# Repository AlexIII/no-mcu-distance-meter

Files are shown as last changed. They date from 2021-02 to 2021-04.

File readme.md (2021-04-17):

# No-MCU Ultrasonic Distance Meter

A Distance Meter that uses no MCU. Bases on ultrasonic ranging module [HC-SR04](https://cdn.sparkfun.com/datasheets/Sensors/Proximity/HCSR04.pdf).

The schematic employs just three standard logic ICs (8-bit counter, divider/oscillator, quad NAND) and a ROM chip (acts as a binary-to-decimal converter).

## Schematic

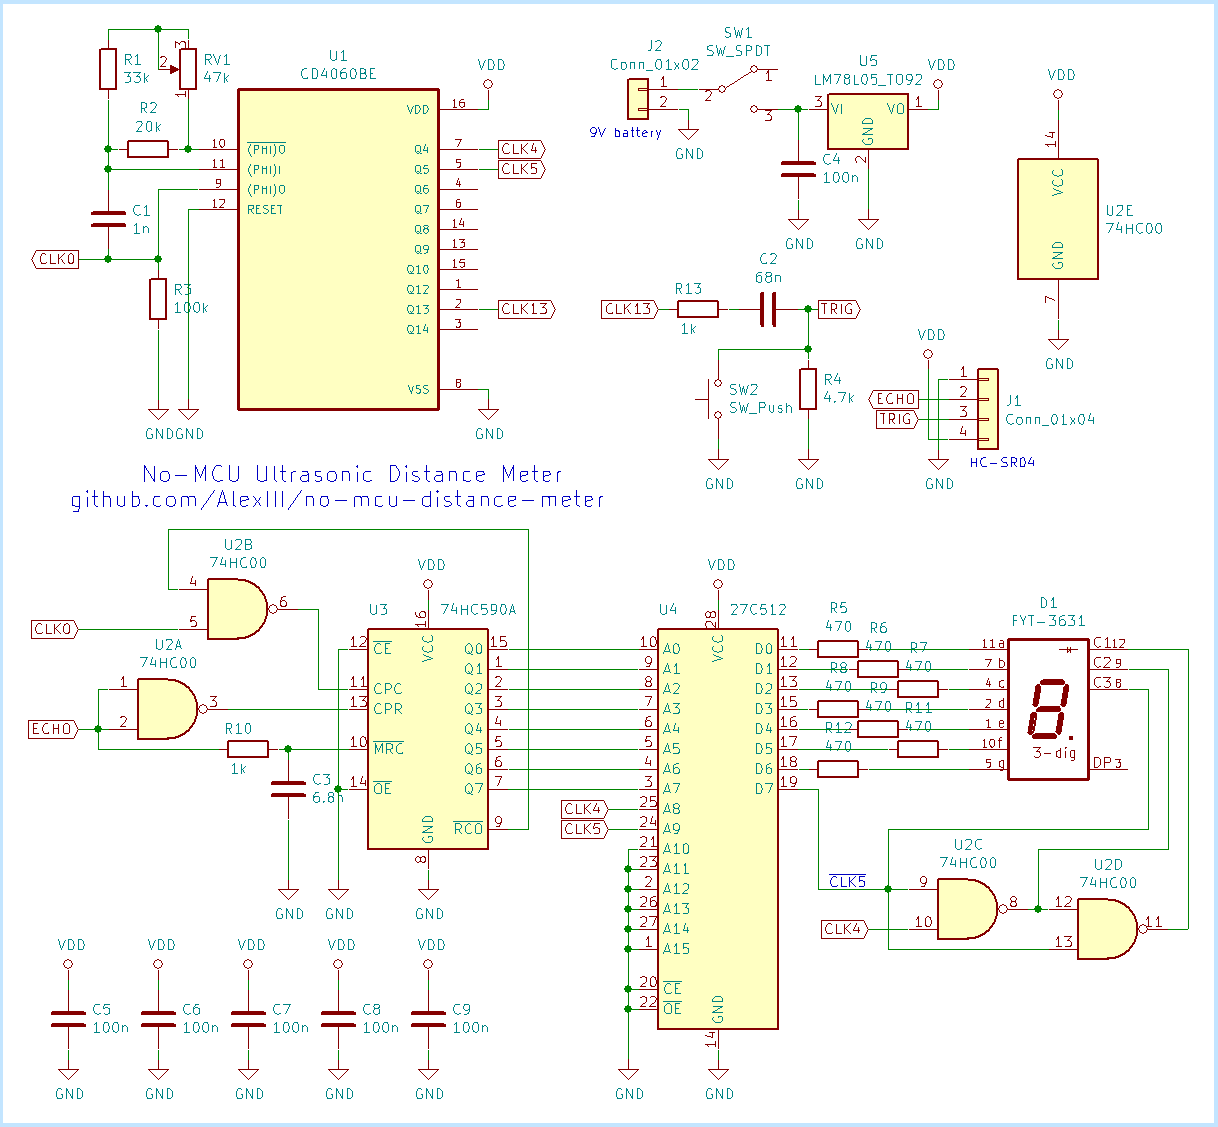
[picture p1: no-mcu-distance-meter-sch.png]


## Photos

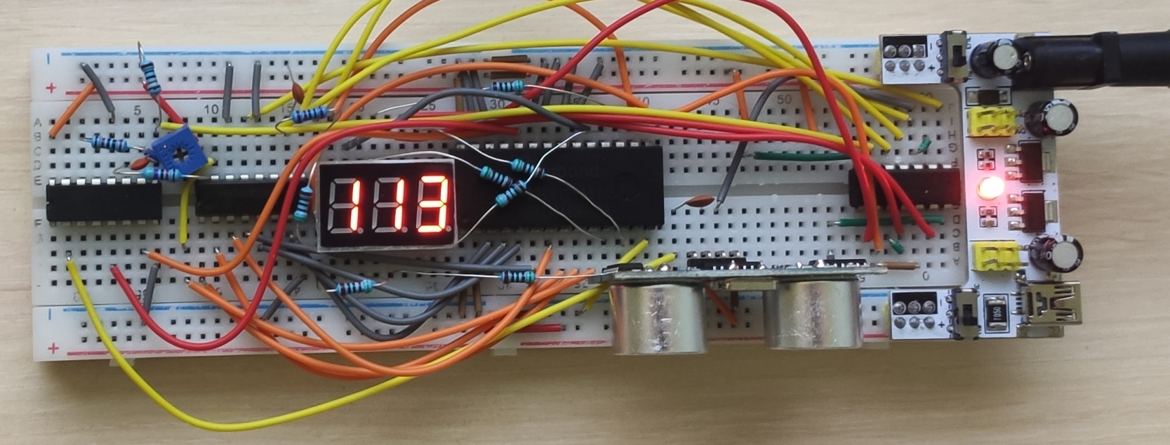
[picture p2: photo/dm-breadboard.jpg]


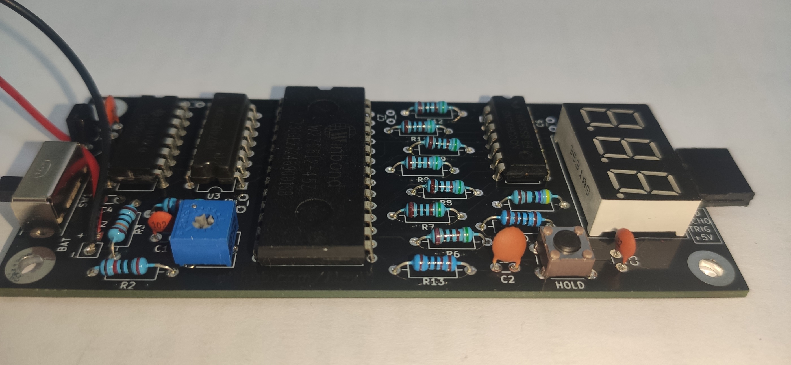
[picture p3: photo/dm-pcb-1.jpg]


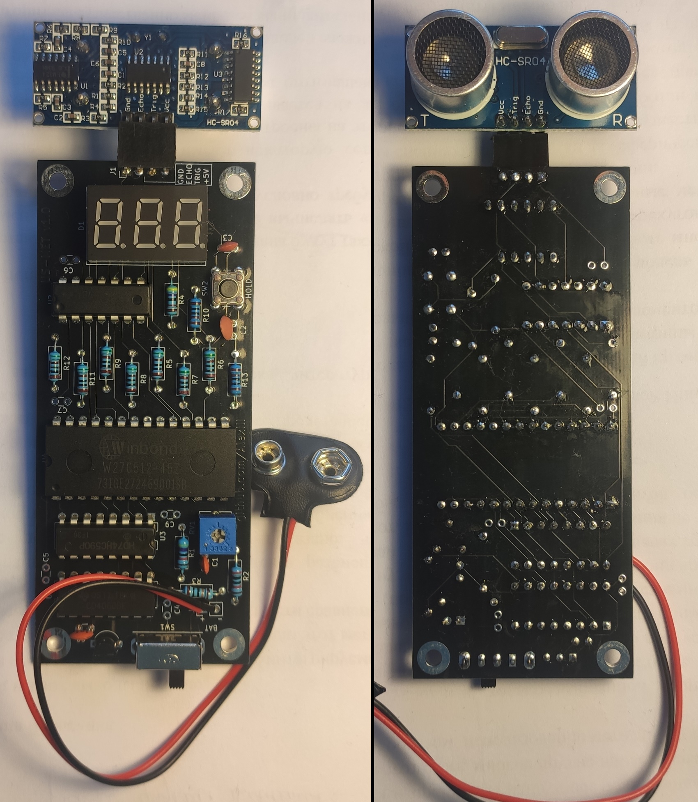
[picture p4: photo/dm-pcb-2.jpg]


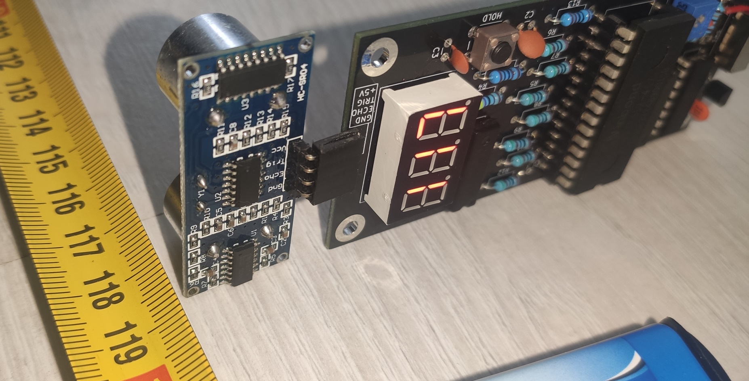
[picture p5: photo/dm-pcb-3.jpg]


## Video

IMAGE ALT TEXT (https://www.youtube.com/watch?v=FPoeiAQJhnc)

## Project files

- `no-mcu-distance-meter-kicad5-prj/`  - KiCAD 5.1 project with the schematic and PCB design
- `eprom-programmer`  - Arduino sketch to program the ROM chip using mega2560 (see the sketch for the connections info).

## License

[CC BY-NC 4.0](https://creativecommons.org/licenses/by-nc/4.0/) © github.com/AlexIII

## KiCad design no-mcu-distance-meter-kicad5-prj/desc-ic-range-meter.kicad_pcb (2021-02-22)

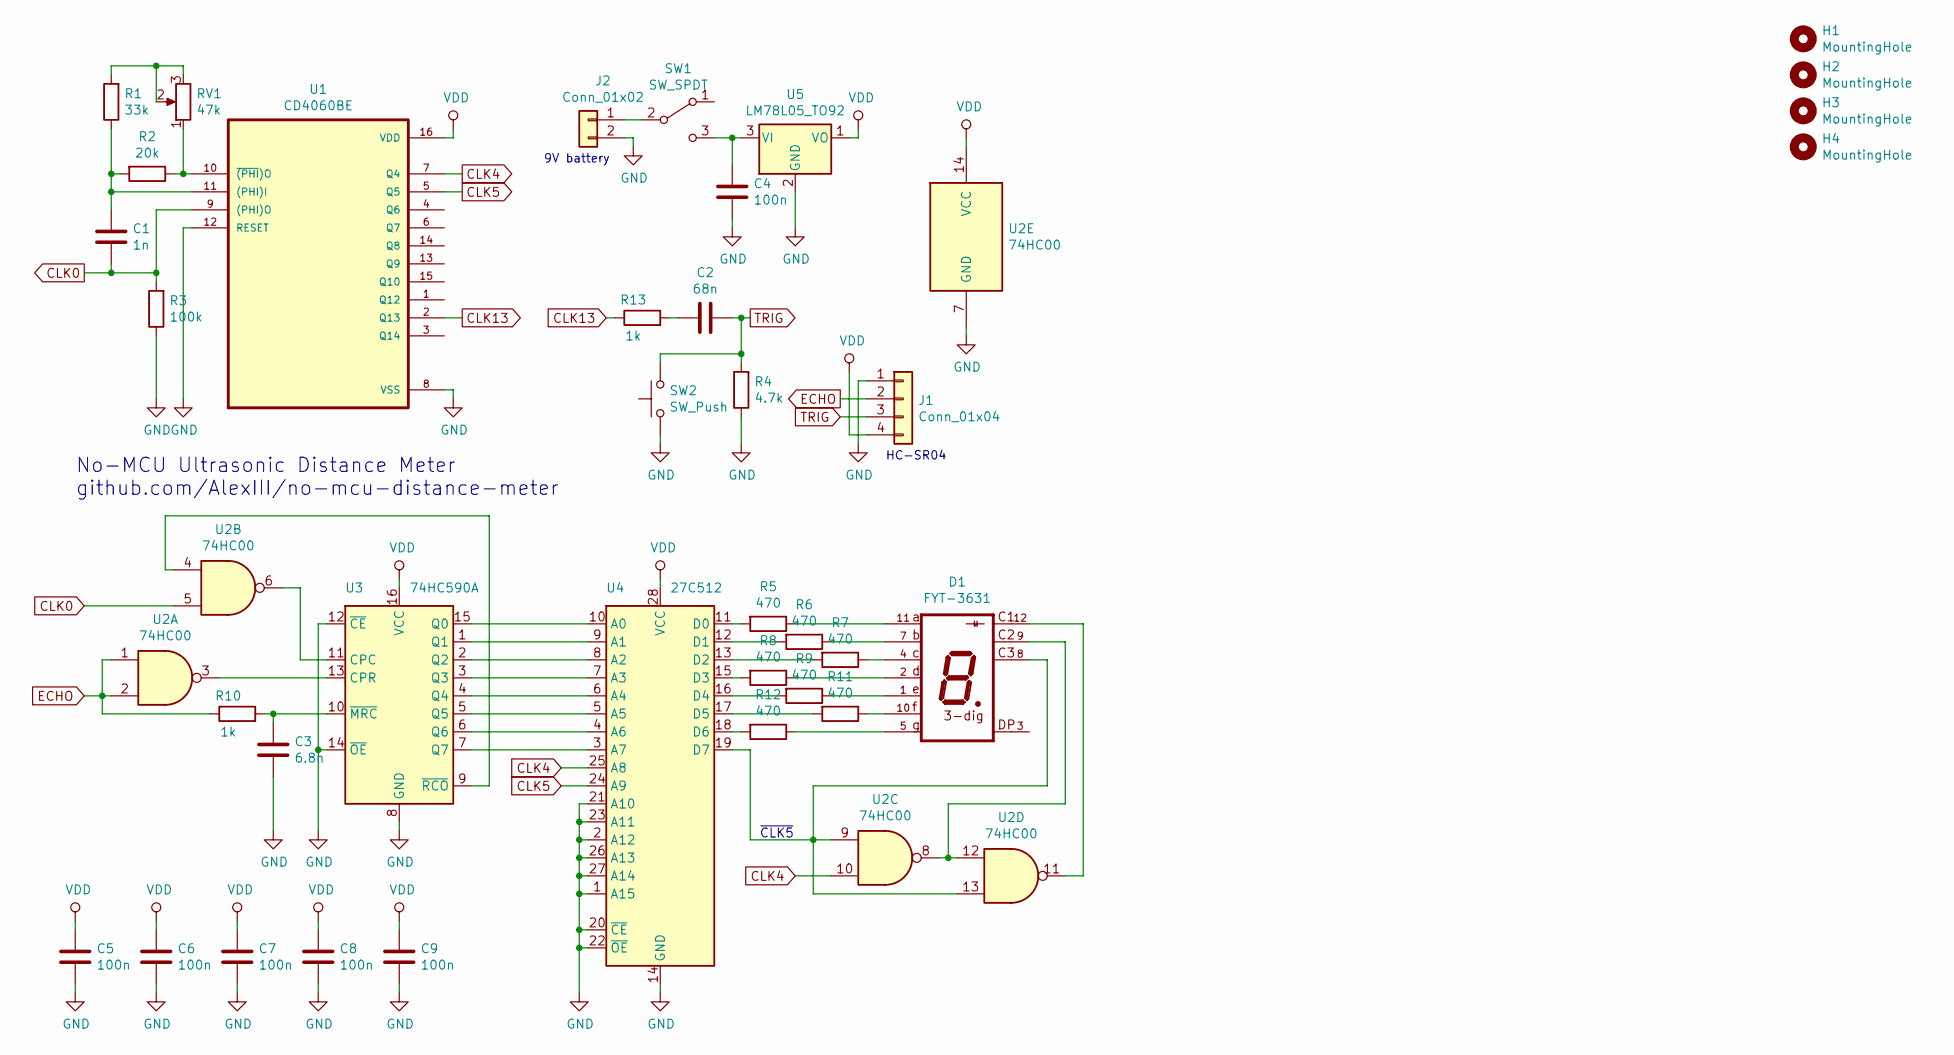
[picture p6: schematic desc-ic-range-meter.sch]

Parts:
C1: 1n; C_Disc_D3.0mm_W1.6mm_P2.50mm
C2: 68n; C_Disc_D3.0mm_W1.6mm_P2.50mm
C3: 6.8n; C_Disc_D3.0mm_W1.6mm_P2.50mm
C4, C5, C6, C7, C8, C9: 100n; C_Disc_D3.0mm_W1.6mm_P2.50mm
D1: FYT-3631
H1, H2, H3, H4: MountingHole; MountingHole_3.2mm_M3_Pad
J1: Conn_01x04; Pin_Header_Angled_1x04_Pitch2.54mm
J2: Conn_01x02; Pin_Header_Straight_1x02_Pitch2.54mm
R1: 33k; R_Axial_DIN0207_L6.3mm_D2.5mm_P10.16mm_Horizontal
R2: 20k; R_Axial_DIN0207_L6.3mm_D2.5mm_P10.16mm_Horizontal
R3: 100k; R_Axial_DIN0207_L6.3mm_D2.5mm_P10.16mm_Horizontal
R4: 4.7k; R_Axial_DIN0207_L6.3mm_D2.5mm_P10.16mm_Horizontal
R5, R6, R7, R8, R9, R11, R12: 470; R_Axial_DIN0207_L6.3mm_D2.5mm_P10.16mm_Horizontal
R10, R13: 1k; R_Axial_DIN0207_L6.3mm_D2.5mm_P10.16mm_Horizontal
RV1: 47k; Potentiometer_Trimmer_ACP_CA6v_Horizontal
SW1: SW_SPDT; SK-12F14
SW2: SW_Push; SW_PUSH_6mm
U1: CD4060BE; DIP-16_W7.62mm
U2: 74HC00; DIP-14_W7.62mm
U3: 74HC590A; DIP-16_W7.62mm
U4: 27C512; DIP-28_W15.24mm
U5: LM78L05_TO92; TO-92_Inline_Wide

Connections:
CLK0: C1.2, R3.2, U1.9 ((PHI)O), U2.5
CLK4: U1.7 (Q4), U2.10, U4.25 (A8)
CLK5: U1.5 (Q5), U4.24 (A9)
CLK13: R13.1, U1.2 (Q13)
ECHO: J1.2, R10.1, U2.1, U2.2
GND: C3.1, C4.1, C5.1, C6.1, C7.1, C8.1, C9.1, J1.1, J2.2, R3.1, R4.1, SW2.1, U1.8 (VSS), U1.12 (RESET), U2.7 (GND), U3.8 (GND), U3.12 (~CE), U3.14 (~OE), U4.1 (A15), U4.2 (A12), U4.14 (GND), U4.20 (~CE), U4.21 (A10), U4.22 (~OE), U4.23 (A11), U4.26 (A13), U4.27 (A14), U5.2 (GND)
unnamed: C1.1, R1.1, R2.2, U1.11 ((PHI)I)
unnamed: C2.2, R13.2
unnamed: C3.2, R10.2, U3.10 (~MRC)
unnamed: C4.2, SW1.3 (C), U5.3 (VI)
unnamed: D1.1, R9.1
unnamed: D1.2, R8.1
unnamed: D1.4, R7.1
unnamed: D1.5, R12.1
unnamed: D1.7, R6.1
unnamed: D1.8, U2.9, U2.13, U4.19 (D7)
unnamed: D1.9, U2.8, U2.12
unnamed: D1.10, R11.1
unnamed: D1.11, R5.1
unnamed: D1.12, U2.11
unnamed: J2.1, SW1.2 (B)
unnamed: R1.2, RV1.2, RV1.3
unnamed: R2.1, RV1.1, U1.10 (~(PHI)O)
unnamed: R5.2, U4.11 (D0)
unnamed: R6.2, U4.12 (D1)
unnamed: R7.2, U4.13 (D2)
unnamed: R8.2, U4.15 (D3)
unnamed: R9.2, U4.16 (D4)
unnamed: R11.2, U4.17 (D5)
unnamed: R12.2, U4.18 (D6)
unnamed: U2.3, U3.13 (CPR)
unnamed: U2.4, U3.9 (~RCO)
unnamed: U2.6, U3.11 (CPC)
unnamed: U3.1 (Q1), U4.9 (A1)
unnamed: U3.2 (Q2), U4.8 (A2)
unnamed: U3.3 (Q3), U4.7 (A3)
unnamed: U3.4 (Q4), U4.6 (A4)
unnamed: U3.5 (Q5), U4.5 (A5)
unnamed: U3.6 (Q6), U4.4 (A6)
unnamed: U3.7 (Q7), U4.3 (A7)
unnamed: U3.15 (Q0), U4.10 (A0)
TRIG: C2.1, J1.3, R4.2, SW2.2
VDD: C5.2, C6.2, C7.2, C8.2, C9.2, J1.4, U1.16 (VDD), U2.14 (VCC), U3.16 (VCC), U4.28 (VCC), U5.1 (VO)

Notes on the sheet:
~CLK5
No-MCU Ultrasonic Distance Meter github.com/AlexIII/no-mcu-distance-meter
HC-SR04
9V battery

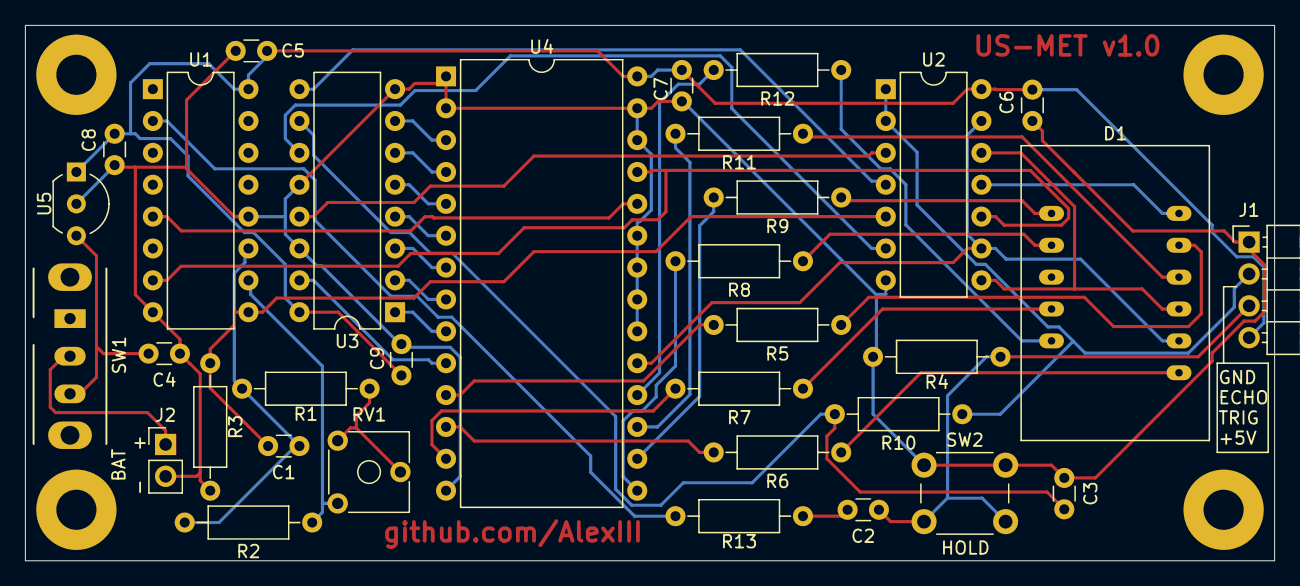
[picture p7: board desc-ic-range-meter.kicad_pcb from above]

Board: 2 copper layers, 99.6 x 42.7 mm, 37 parts (0 on the bottom side), 43 nets.

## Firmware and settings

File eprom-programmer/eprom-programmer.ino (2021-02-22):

/**
 * No-MCU Ultrasonic Distance Meter - ROM programmer (W27C512)
 * Arduino mega2560
 */

// Select ONE of the folowing:
//#define CHIP_EARSE
#define CHIP_PROGRAM

//------- ROM connections ------

// ROM OE pin
#define ENABLE_14V_PIN  38  //14v OE pin control (HIGH - enabled)
#define ENABLE_12V_PIN  39  //12v OE pin control (HIGH - enabled)
#define ENABLE_5V_PIN   40  //5v OE pin control (HIGH - enabled)
#define DISABLE_HIGH_VOLTAGE do {digitalWrite(ENABLE_14V_PIN, LOW); digitalWrite(ENABLE_12V_PIN, LOW); digitalWrite(ENABLE_5V_PIN, LOW);} while(0)
#define OE_HIGH do {DISABLE_HIGH_VOLTAGE; digitalWrite(ENABLE_5V_PIN, HIGH);} while(0)
#define OE_LOW do {DISABLE_HIGH_VOLTAGE; digitalWrite(ENABLE_5V_PIN, LOW);} while(0)
#define PE_HIGH do {DISABLE_HIGH_VOLTAGE; digitalWrite(ENABLE_12V_PIN, HIGH);} while(0)
#define EE_HIGH do {DISABLE_HIGH_VOLTAGE; digitalWrite(ENABLE_14V_PIN, HIGH);} while(0)

// ROM CE pin
#define CE_PIN          41
#define CE_HIGH digitalWrite(CE_PIN, HIGH)
#define CE_LOW digitalWrite(CE_PIN, LOW)

// ROM A0-A7 => Arduino 22-29 (PORTA)
// ROM A8-A15 => Arduino 37-30 (yes, backwards) (PORTC)
#define SET_ADDR(addr) do{ PORTA = uint8_t(addr); PORTC = uint16_t(addr) >> 8; } while(0)
// ROM Q0-Q7 => Arduino 49-42 (yes, backwards) (PORTL)
#define GET_DATA() (DDRL = 0x00, PORTL = 0x00, PINL)
#define SET_DATA(data) do{ PORTL = data; DDRL = 0xFF; } while(0)

//------- ------

uint8_t eeRead(const uint16_t addr) {
  OE_HIGH;        //disable outputs and possible program/erase mode
  GET_DATA();     //set port to input
  CE_LOW;         //enable chip
  SET_ADDR(addr); //set address
  OE_LOW;         //enable outputs
  _delay_us(2);
  const uint8_t data = GET_DATA();  //read data
  OE_HIGH;        //disable outputs
  return data;
}

void eeProgram(const uint16_t addr, const uint8_t data) {
  CE_HIGH;        //disable chip
  SET_ADDR(addr); //set address
  PE_HIGH;        //set programming voltage
  SET_DATA(data); //set data
  _delay_us(2);

  //programming pulse
  CE_LOW;
  _delay_us(200);
  CE_HIGH;

  OE_HIGH;        //disable programming voltage
}

void eeErase() {
  CE_HIGH;        //disable chip
  SET_ADDR(0x0200U);
  EE_HIGH;        //set erasing voltage
  SET_DATA(0xFF);
  _delay_us(2);
  
  //erasing pulse
  CE_LOW;
  _delay_ms(200);
  CE_HIGH;

  OE_HIGH;        //disable erasing voltage
}

bool checkErased(const uint16_t chipSize) {
  bool res = true;
  for(uint16_t addr = 0; addr < chipSize || chipSize == 0; ++addr) {
    const uint8_t data = eeRead(addr);
    if(data != 0xFF) {
      res = false;
      Serial.print(F("Erase check error at 0x"));
      Serial.print(addr, HEX);
      Serial.print(F(" Data = "));
      Serial.print(int(data), HEX);
      Serial.print(F(" (expected 0xff)"));
      Serial.println();
      break;
    }
    if(chipSize == 0 && addr == 0xFFFF) break;
  }
  return res;
}

#define CHIP_SIZE uint16_t(0)

void setup() {
  Serial.begin(250000);
  Serial.println(F("Started."));
  
  //control
  pinMode(ENABLE_14V_PIN, OUTPUT);
  pinMode(ENABLE_12V_PIN, OUTPUT);
  pinMode(ENABLE_5V_PIN, OUTPUT);
  pinMode(CE_PIN, OUTPUT);
  CE_HIGH;   //disable chip select
  OE_HIGH;  //disable outputs

  //address
  DDRA = 0xFF;
  DDRC = 0xFF;
  
  DISABLE_HIGH_VOLTAGE;

  delay(10);

#if defined(CHIP_EARSE)
  eeErase();
  delay(10);
  const bool eraseOk = checkErased(CHIP_SIZE);
  if(eraseOk) Serial.println(F("Erase check ok."));
  else Serial.println(F("Erase check error."));
#elif defined(CHIP_PROGRAM)
  programBinToDecDecoder(true);
  Serial.println(F("Write finished."));
  const bool writeOk = programBinToDecDecoder(false);
  if(writeOk) Serial.println(F("Write check ok."));
  else Serial.println(F("Write check error."));
#else
  Serial.println(F("No operation selected."));
#endif

  Serial.println(F("Done."));

//  for(int i = 0; i < 0x100; ++i) {
//    Serial.print((int)eeRead(i), HEX);
//    Serial.print(' ');
//  }
  
  Serial.println();
}


void loop() {
}



// Binary to decimal decoder
uint8_t decimalDigitToSegmentCode(const uint8_t digit) {
  switch(digit) {
    case 0: return 0b0111111;
    case 1: return 0b0000110;
    case 2: return 0b1011011;
    case 3: return 0b1001111;
    case 4: return 0b1100110;
    case 5: return 0b1101101;
    case 6: return 0b1111101;
    case 7: return 0b0000111;
    case 8: return 0b1111111;
    case 9: return 0b1101111;
    default: return 0b1000000; // "-"
  }  
}

bool programBinToDecDecoder(const bool programm) {
  bool checkOk = true;
  uint8_t dpow = 1; //powers of 10
  for(uint8_t dp = 0; dp < 4; ++dp) { //digit place
    for(uint16_t n = 0; n < 0x100; ++n) { //for all input values 0..255
      const uint16_t addr = ((
          dp == 0b00? 0b10:
          dp == 0b01? 0b01:
          dp == 0b10? 0b00:
                      0b11
        ) << 8) | n;  // input dd vvvvvvvv
      const uint8_t digitCode = decimalDigitToSegmentCode( n == 255? 0xFF : ((n/dpow)%10) );  //7-bit output code for a digit
      const uint8_t data = (dp == 3? 0 : digitCode) | (((~addr) >> 2) & 0x80);
      if(programm) eeProgram(addr, data);
      else {
        const uint8_t rd = eeRead(addr);
        if(rd != data) {
          Serial.print(F("Write check error at 0x"));
          Serial.print(addr, HEX);
          Serial.print(F(" Read = 0x"));
          Serial.print(int(rd), HEX);
          Serial.print(F(", expected 0x"));
          Serial.print(int(data), HEX);
          Serial.println();
          checkOk = false;
          break;
        }
      }
      
    }
    if(!checkOk) break;
    dpow *= 10;
  }

  return checkOk;
}
